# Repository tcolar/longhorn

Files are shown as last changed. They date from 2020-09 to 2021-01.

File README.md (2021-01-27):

# Longhorn keyboard build

What is the longhorn keyboard ?

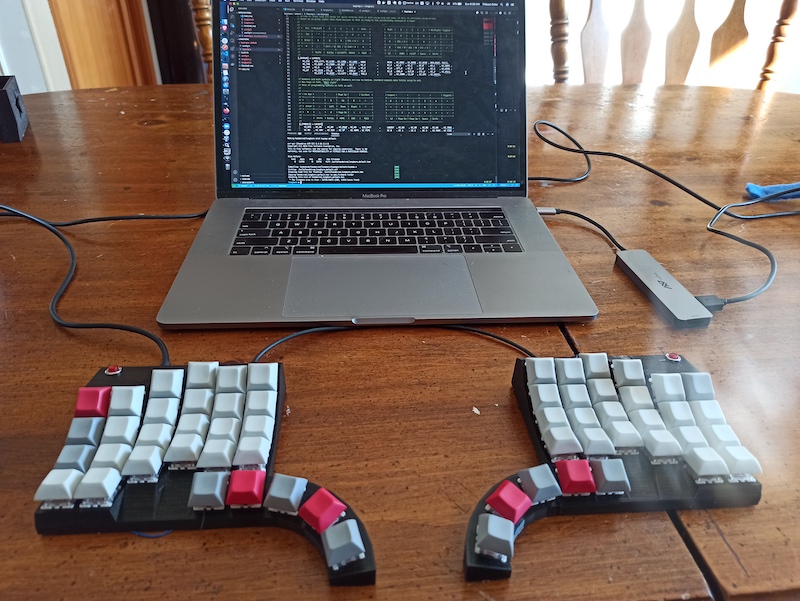
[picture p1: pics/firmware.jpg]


It's a split, sculpted, ortholinear keyboard.

It's a modified version of this keyboard by u/cyanophage : https://www.reddit.com/r/ErgoMechKeyboards/comments/i8e9xv/my_first_split_my_own_design/

Almost all the credits go to him, I ust modified his design, mostly to have a different thumb keys layout (fan out).

### Why is it called longhorn?

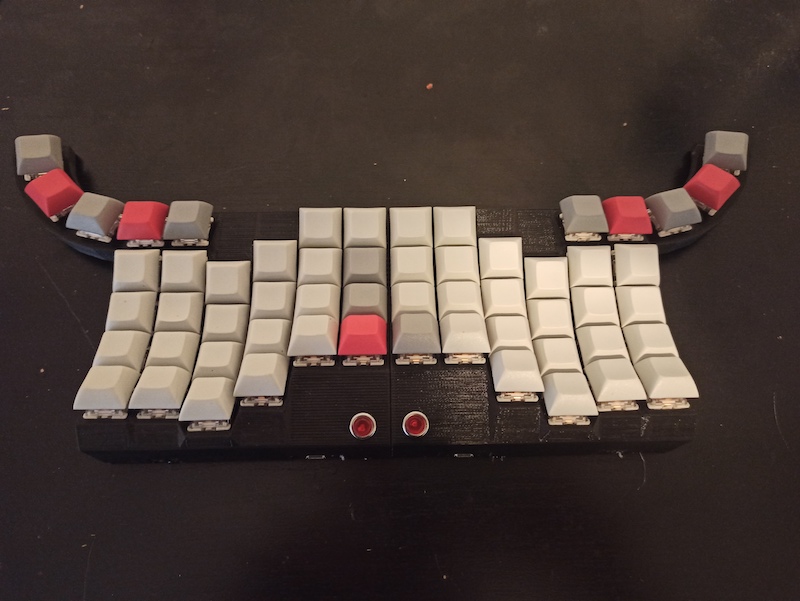
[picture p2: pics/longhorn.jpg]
longhorn
because: 

### Design

I started with the design by u/cyanophage and made some modifications.

- Removed the existing thumb keys.
- Replaced with a new circular thumb clusters.
- Added a caddy for the pro-micro (slightly different than the eliteC )
- Added a different jack caddy (jack module)

I used [OpenScad](https://www.openscad.org/) to tweak the design, in a linux VM as it's not signed to run on OSX.

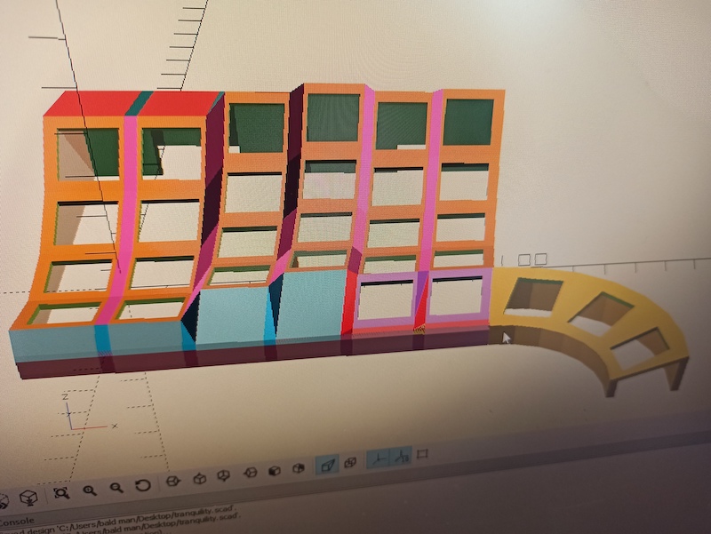
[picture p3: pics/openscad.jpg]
openscad


See the [Design](/design) folder for the Scad and STL files

### Printing

Here is the STL [kb.stl](design/kb.stl), printed mirrored for the other hand.

I printed with my old Robo3D+ using black PLA filament.

I used [Cura](https://ultimaker.com/software/ultimaker-cura) for the slicing.

I print via [octopi](https://octoprint.org/) (raspberry pi connected to the printer).

Settings I used:

- Bed Temp: 50c
- Extruder temp: 210c
- Quality : fine (0.2mm)
- Support: yes, zig-zag. This needs good support and zig zag is fast and easy to remove
- Adhesion: used a raft, adds almost an hour to the print, but support adhesion to the bed was an issue without it.

Print time: ~ 9 hours per side.

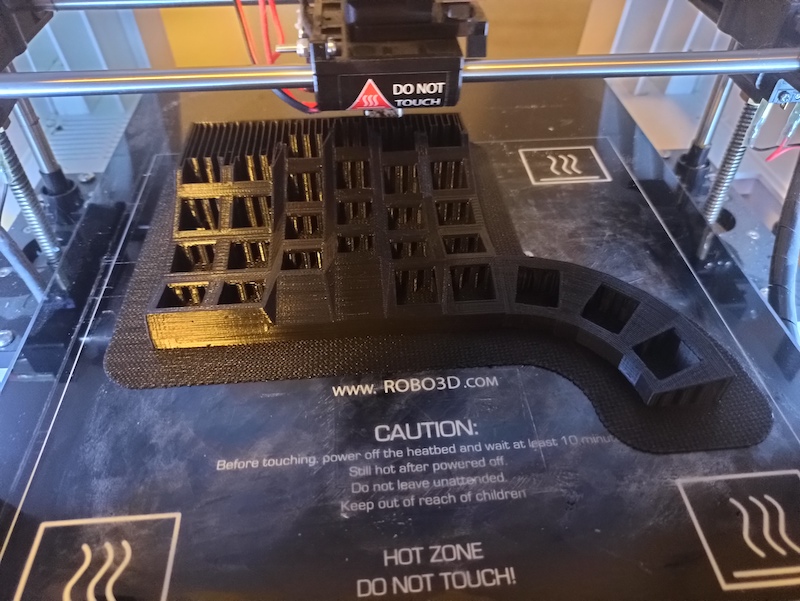
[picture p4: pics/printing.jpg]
printing


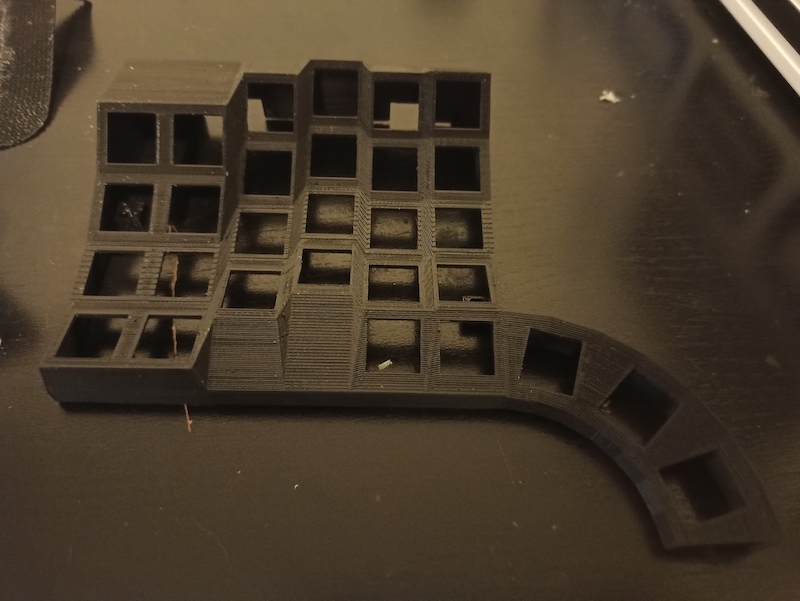
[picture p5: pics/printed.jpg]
printed


### Parts

- wire 22awg solid : https://www.amazon.com/gp/product/B07TX6BX47/ref=ppx_yo_dt_b_asin_title_o05_s00?ie=UTF8&psc=1
- Keyboard switches(60+), for example: https://www.amazon.com/gp/product/B07X3SYQMV/ref=ppx_yo_dt_b_asin_title_o09_s00?ie=UTF8&psc=1
- 4pins TRSS jacks (2+): https://www.amazon.com/gp/product/B08331SNXD/ref=ppx_yo_dt_b_asin_title_o00_s00?ie=UTF8&psc=1
- 1N4148 Diodes (60+) : https://www.amazon.com/gp/product/B06XB1R2NK/ref=ppx_yo_dt_b_asin_title_o02_s01?ie=UTF8&psc=1
- Keycaps (60+): Any but cheap ones for starters: https://www.amazon.com/gp/product/B07GP29DQF/ref=ppx_yo_dt_b_asin_title_o02_s02?ie=UTF8&psc=1
- ProMicro controllers (2+) : https://www.amazon.com/gp/product/B08BJNV1J3/ref=ppx_yo_dt_b_asin_title_o02_s02?ie=UTF8&psc=1
- Optional: Ribbon wire: https://www.amazon.com/gp/product/B07PBGVCNL/ref=ppx_yo_dt_b_asin_title_o02_s00?ie=UTF8&psc=1
- Optional: small reset buttons: https://www.amazon.com/gp/product/B07ZV3PB26/ref=ppx_yo_dt_b_asin_title_o07_s00?ie=UTF8&psc=1

### Tools:

- Soldering iron + solder
- Small wire cutters / strippers
- Hot glue gun
- Helping hands really helps : https://www.amazon.com/Neiko-01902-Adjustable-Magnifying-Alligator/dp/B000P42O3C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

### Switches

Install all the switches

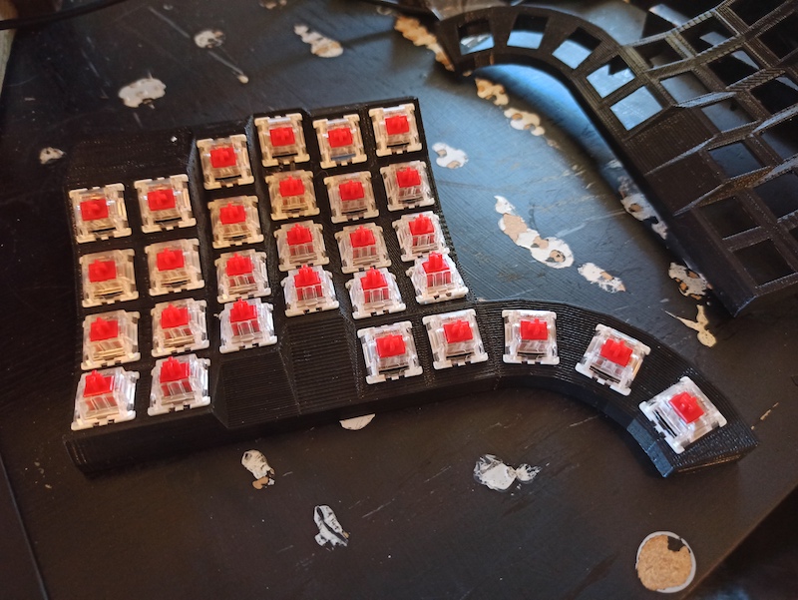
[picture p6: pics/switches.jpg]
switches


Then glue them in place:

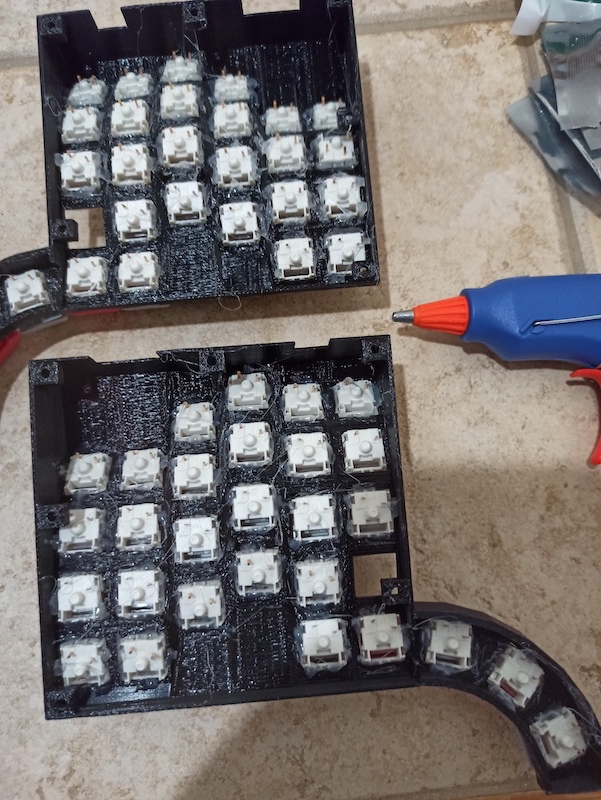
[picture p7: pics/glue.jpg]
glue


Testing pinky/thumb placement :

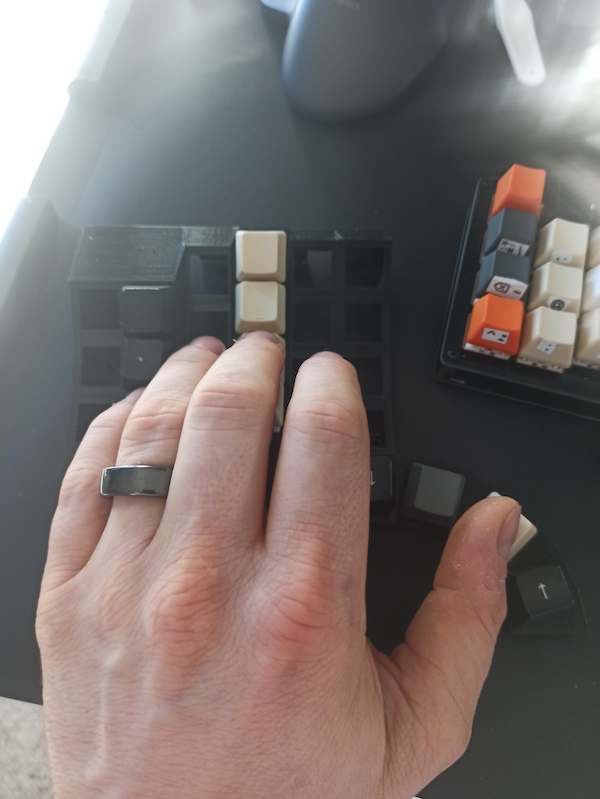
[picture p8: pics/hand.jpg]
hand


### Install keycaops

You can do this either now or after the wiring, but better know if anything is off ASAP.

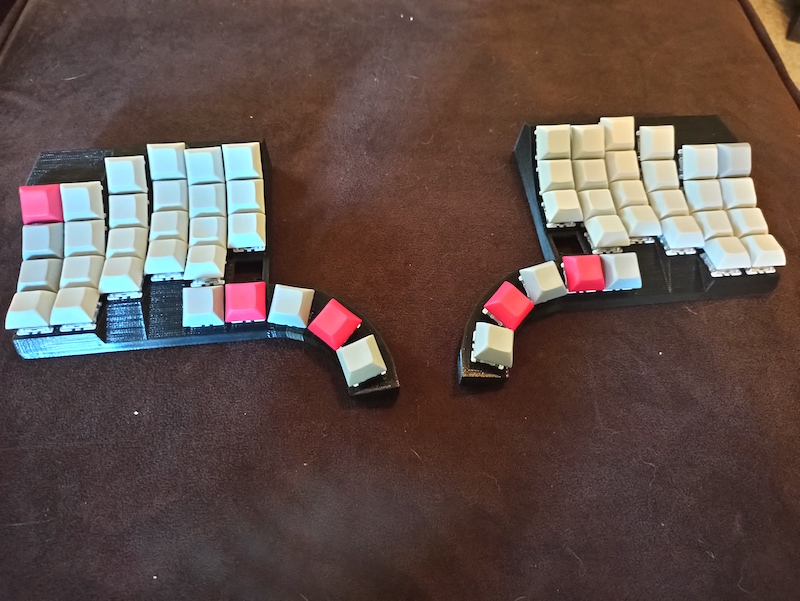
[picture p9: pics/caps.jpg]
caps


### Wiring

This is the part that is a ton of work.

My matrix is 6 cols \* 5 rows (per hand)
The thumb cluster is treated as row5 with keys in cols 2-6.

#### Rows

First I wired the rows, each key gets a diode to the row to avoid ghosting.

Make a little loop with each diode and solder it to each key.

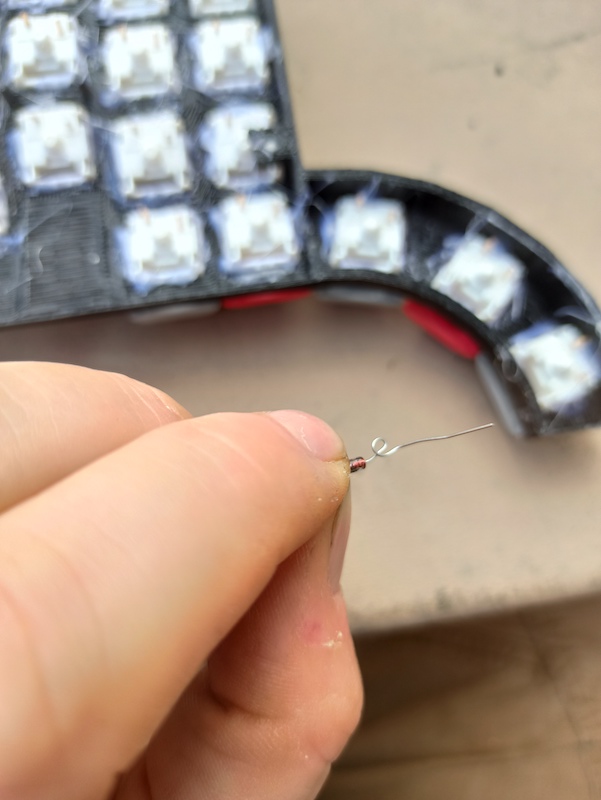
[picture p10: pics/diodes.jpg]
diodes


Then I take a piece of wire and mark the diode pins location and use a razor knife to expose the wire core. Make surer to use solid wire for this, stranded wire would be a pain.

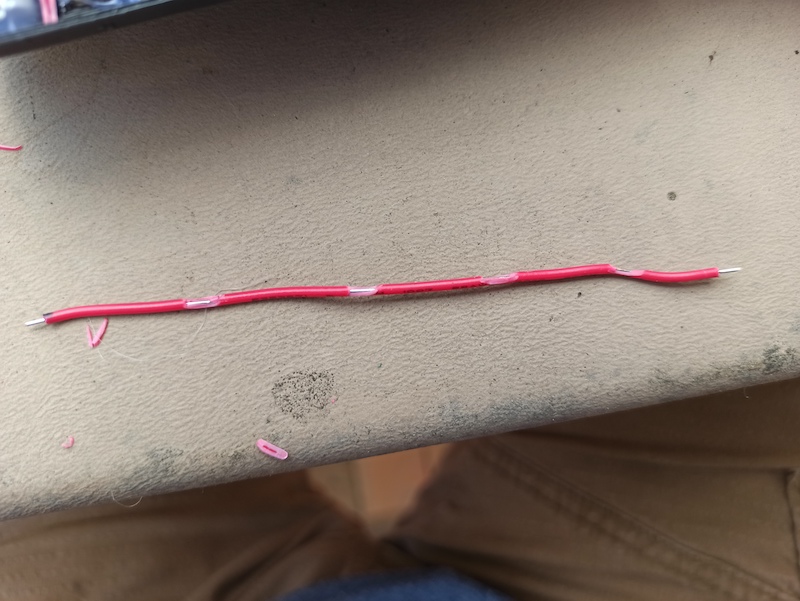
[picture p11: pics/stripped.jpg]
stripped


Then solder the diodes to the wire, and that's one row :
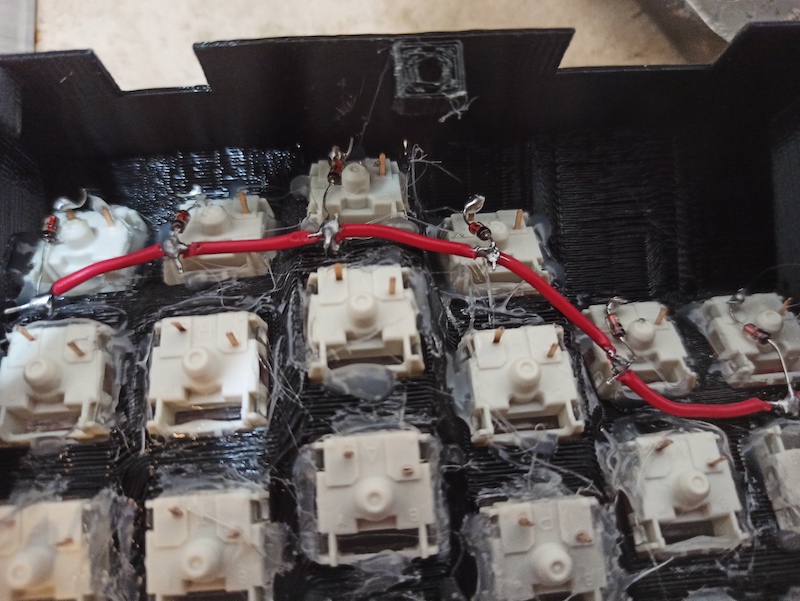
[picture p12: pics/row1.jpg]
row1


Repeat for all rows
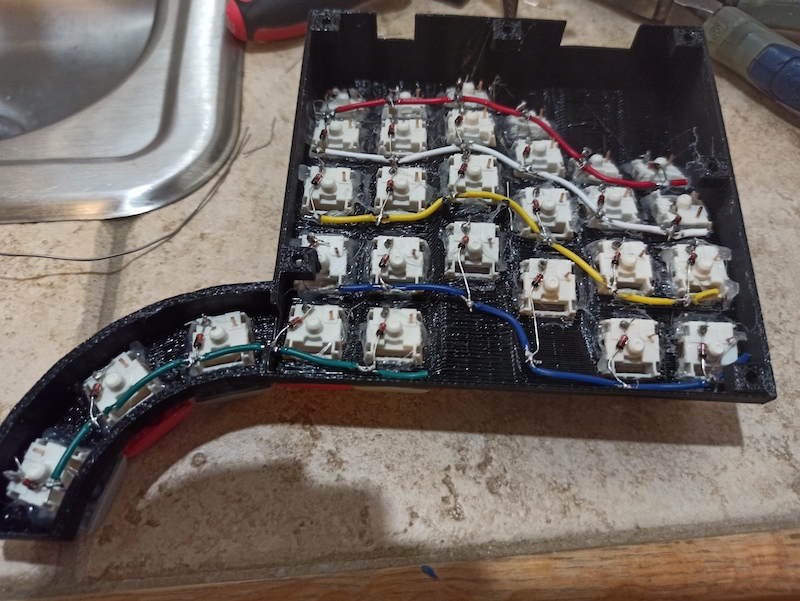
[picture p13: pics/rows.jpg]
rows


### Columns

For the columns we don't need any diodes just connect with wire:

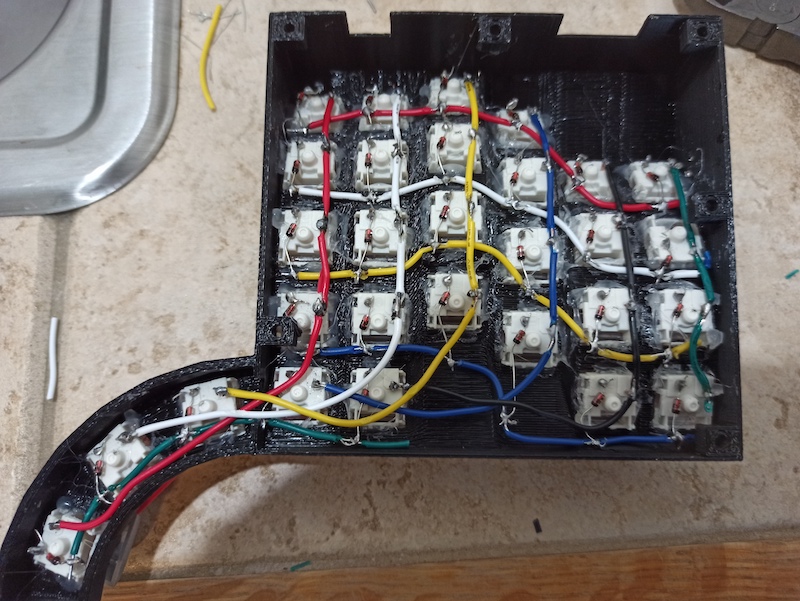
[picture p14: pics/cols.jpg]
cols


### Controller

Printed a caddy for the controller and jacks, see [micro.stl](design/micro.stl)

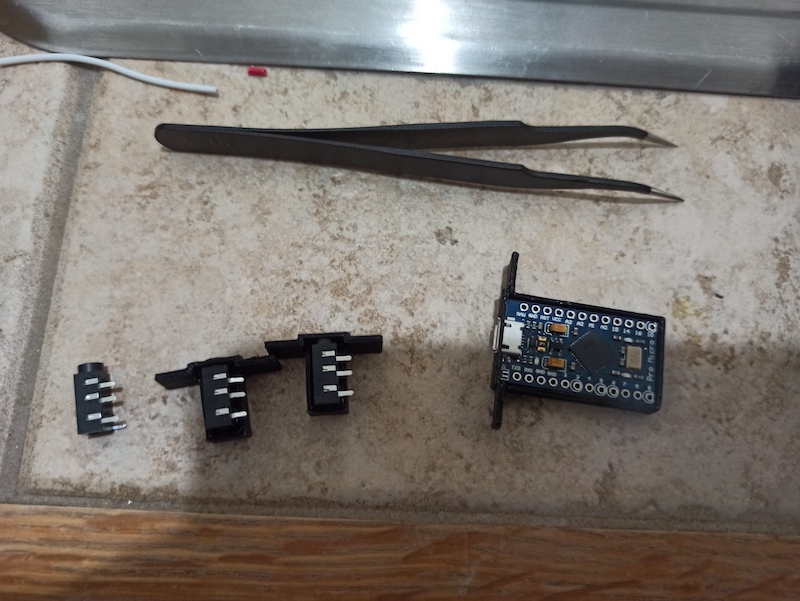
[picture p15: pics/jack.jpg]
jack


Wiring the controller os pretty difficult as it's very tiny and close together.

I used ribbon wire for this as it's less messy.

Here are the pins layout for the pro micro:
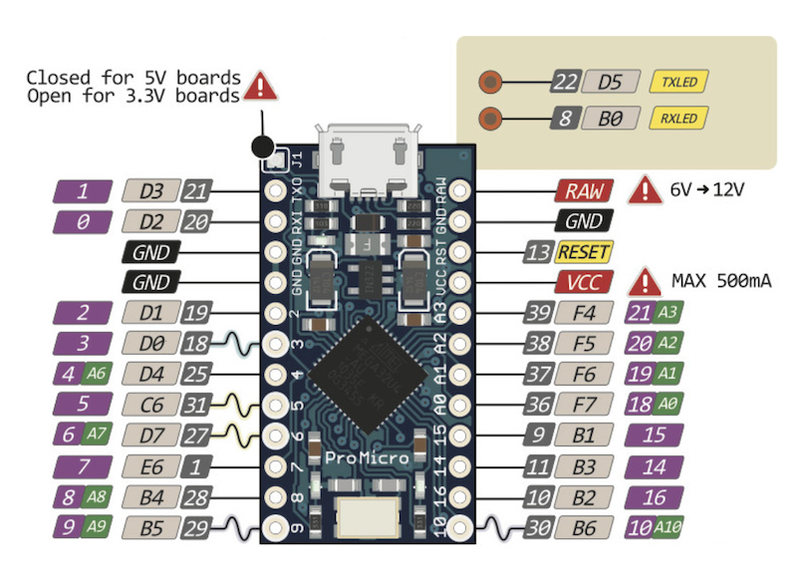
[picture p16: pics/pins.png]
pins


So first I soldered ribbon wires to the pro micro:

Best is to apply solder to the pro micro pins (little solder bubble), apply a bit of solder to the end of the wire, and then solder them together one by one.

Be careful not to have two pins getting soldered together.

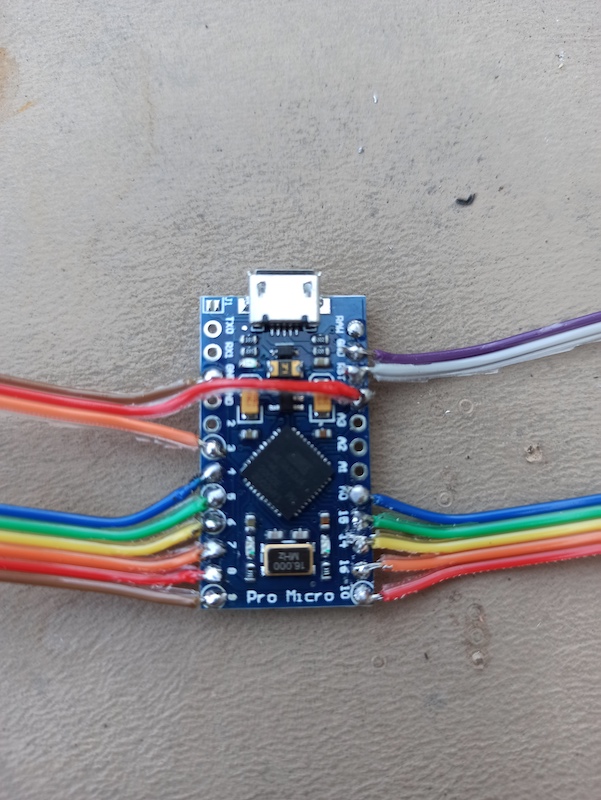
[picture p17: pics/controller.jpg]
controller


What I have here is:

- top right : purple(GND) and white(RESET) wires are and going to the reset button.
- top left : orange(pin3 a.k.a D0), red(VCC) and brown(GND), goes to the TRSS jack connecting the two halves.
- bottom right : wires going to the 5 columns.
- bottom left : wires going to the 6 rows.

Wired up, with the TRSS & controller caddies glued:

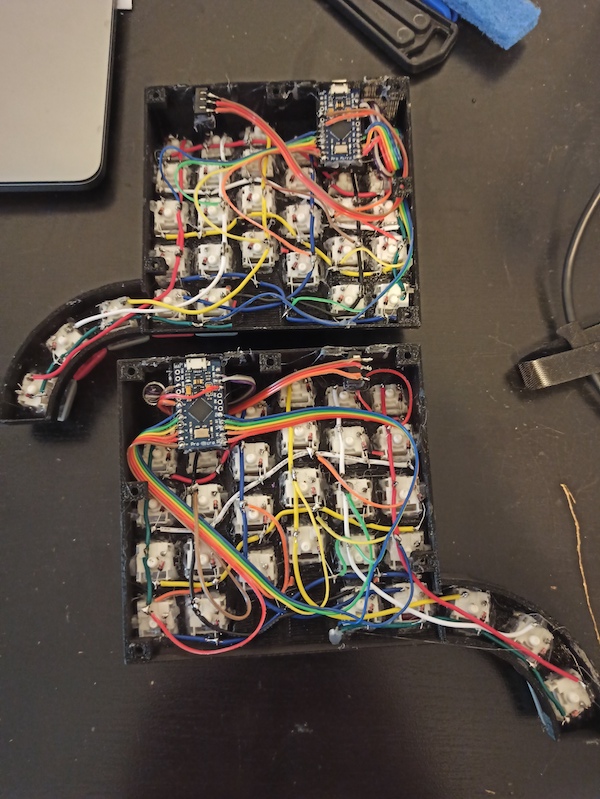
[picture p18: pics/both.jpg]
both


### Jacks & Reset button

I glued the [jack.stl](design/jack.stl) caddies and wired the jacks.

Note: I messed the jacks up and had to redo them as I initially let some hot glue get inside the jack plug and they were not working.

I had not planned for reset buttons, so I drilled a hole to add them, I highly recommend reset buttons as it makes it so much easier to reflash your firmware as you figure out your keymap.

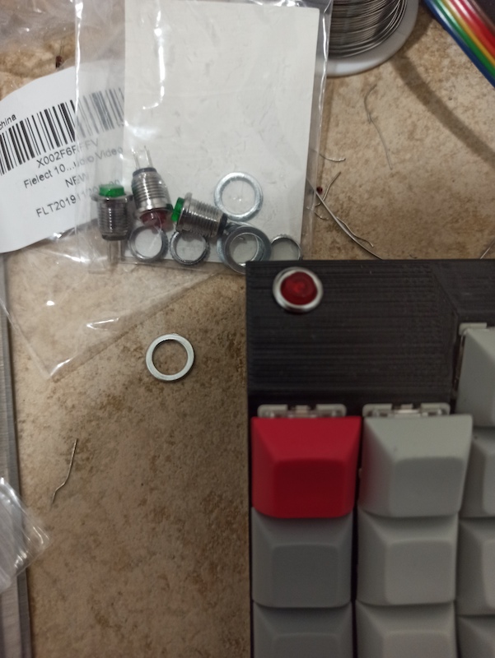
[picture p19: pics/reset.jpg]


### Firmware

Up next is the firmware.

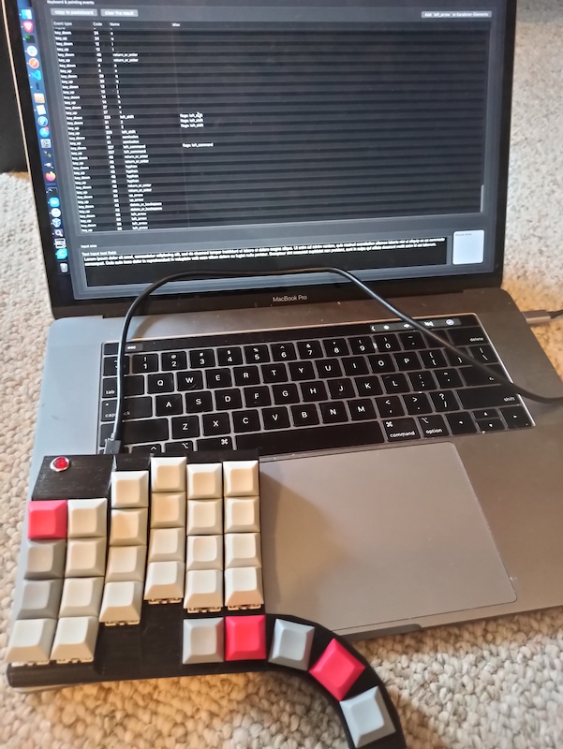
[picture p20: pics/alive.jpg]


I created my 5\*6 matrixes and my custom layout and flashed them.

#### rules.mk

in [rules.mk](/qmk_firmware/keyboards/handwired/longhorn/rules.mk), most important parts:

```yaml
# config for pro micro :
MCU = atmega32u4
BOOTLOADER = caterina
# Yes, this is a split KB :
SPLIT_KEYBOARD = yes
```

#### config.h

First [config.h](/qmk_firmware/keyboards/handwired/longhorn/config.h), the most important bits are:

```c
// Specify what micro-controller pins are hoked up to rows and cols:
// Note: the pin names are no what is labelled on the pro-micro, see
// the pin diagram above in this page for reference.
#define MATRIX_ROW_PINS \
    { B6, B2, B3, B1, F7 }
#define MATRIX_COL_PINS \
    { B4, B5, E6, D7, C6, D4 }
// Specify the pin used for serial communicationbetween the halves,
// via the audio cable.
#define SOFT_SERIAL_PIN D0      // pin #3
// Specify our diodes directions, if you set that wrong, keys won't work
#define DIODE_DIRECTION COL2ROW
```

#### longhorn.h

[longhorn.h](/qmk_firmware/keyboards/handwired/longhorn/longhorn.h) defines our key matrix and how keys are laid out on each half.

Note that I wired up my columns "mirrored" (left to right on left hand, right t eft on right hand), so I had to invert the right hand entries in my layout to get the correct mapping, see the file for more info.

#### keymap.c

Finally [keymap.c](/qmk_firmware/keyboards/handwired/longhorn/keymaps/default/keymap.c) contains our keyboard layout (with multi layers etc ...)

Just open the file to see my current layout.

#### Flashing

First I built my firmware with build.sh

```
qmk compile -kb handwired/longhorn -km default
```

And then flashed it using [QMK Toolbox](https://qmk.fm/toolbox/)

It works best to use auto-flash and then press the kb reset button (auto-flash because pro-micro only gives you ~8 seconds to flash after pressing reset).

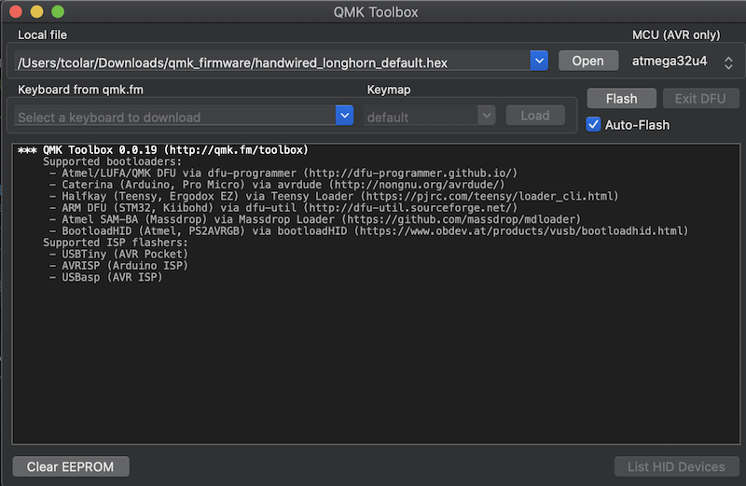
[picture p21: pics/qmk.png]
qmk


### End result:

It works great, next up is figuring out some baseplate and tenting, maybe 3D printed, maybe wood.

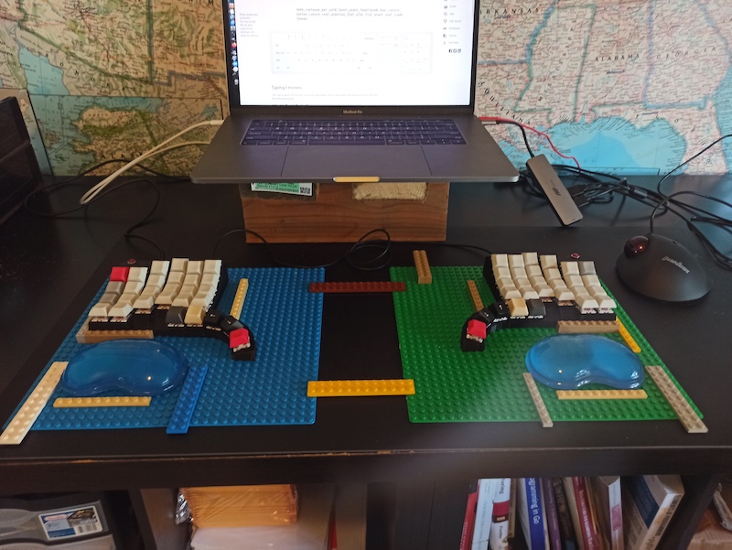
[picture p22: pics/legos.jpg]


Once I found the spacing and angle I like I made a "plank" for it, and my wife painted our pets on it.

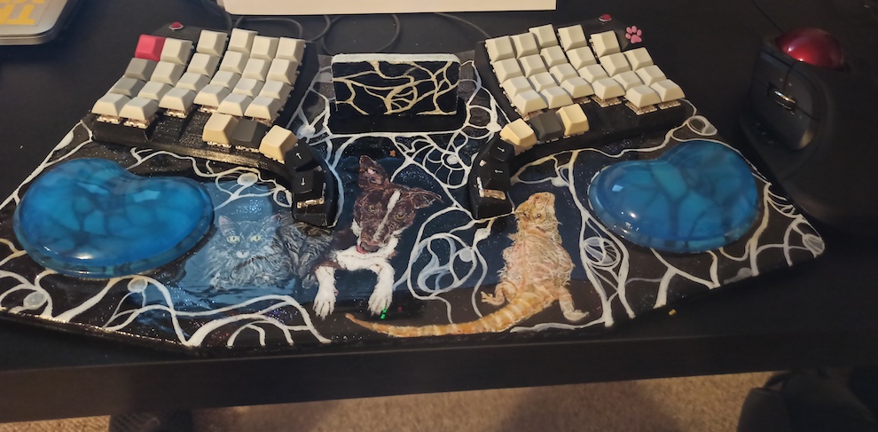
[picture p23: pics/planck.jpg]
plank


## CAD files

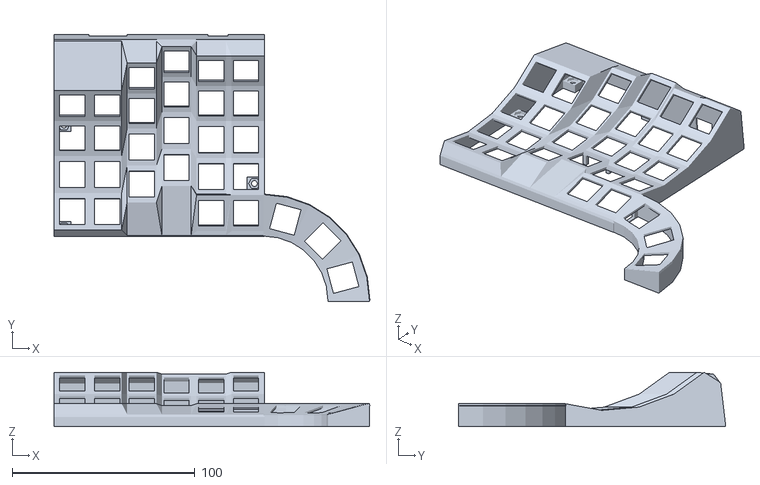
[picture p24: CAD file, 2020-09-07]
design/kb.stl
172.8 x 146.0 x 29.7

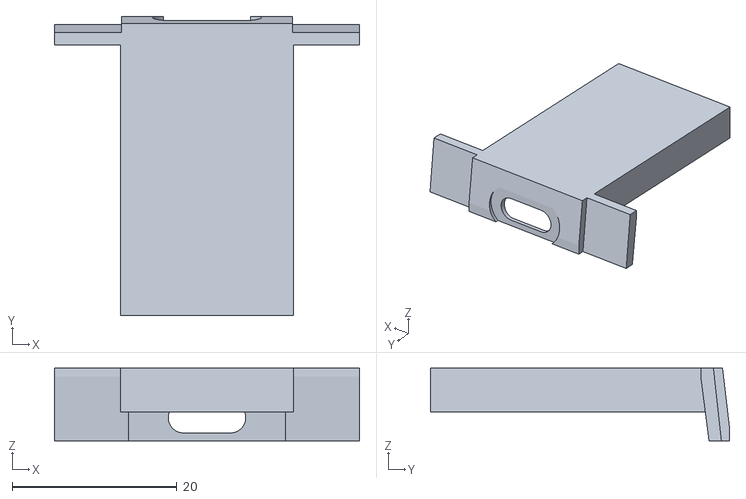
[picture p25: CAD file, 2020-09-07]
design/micro.stl
37.0 x 36.3 x 8.80

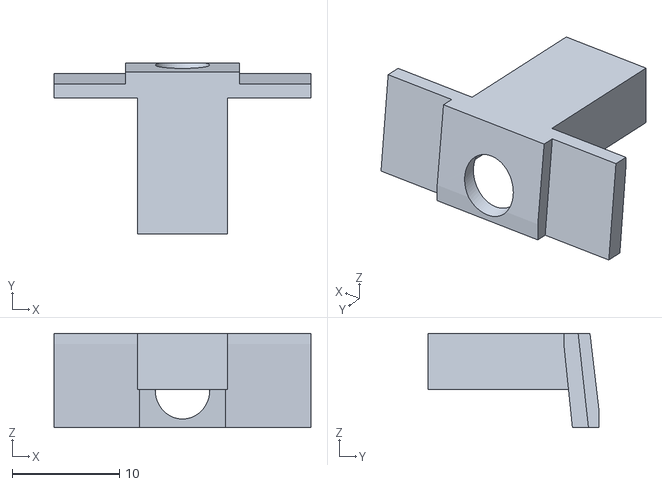
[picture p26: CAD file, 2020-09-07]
design/jack.stl
24.0 x 16.0 x 8.80

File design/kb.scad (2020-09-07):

kw=13.92; // size of hole for switch x
kd=14.42; // size of hole for switch y
sepx=19; // x spacing between the switches
sepy=20.6; // y spacing between the switches
th=1.5; // thickness of top
bth=1; // bottom thickness
gap=1.5; // x width of bits between keys

fingers = [0,0,15,24,19,19,19]; // controls y adjustment of columns
thumbs = [0,0,0,0,0,0,0];
dips = [0,0,0,1,1,0,0]; // controls z adjustment of columns
fronty=-33.5;  // y position of front
reary=76;      // y position of rear
supports = [fronty,-10,10,30,76];
edgex=2;


module rotate_about_xy(x, y, pt) {
  translate(pt)
    rotate([x, y, 0])
      translate(-pt)
        children();
}  

module rotate_about_z(z, pt) {
  translate(pt)
    rotate([0, 0, z])
      translate(-pt)
        children();
}  
module rotate_about_xy_off(x, y, pt,off) {
  translate(pt+off)
    rotate([x, y, 0])
      translate(-pt)
        children();
}  

bigR = 77;  // controls the radius of the curvature of the top. higher is less curve
rx = 2*asin(sepy/(2*bigR));
ry = 2*asin(sepx/(2*bigR));

// top plate

cubex=0.01;
cube2=cubex/2;
cubey=0.1;
vth=0.8;
baseline = -5; // controls where the bottom is and therefore overall height
frontdip=5; // height of bit at the front. higher numbers makes it lower
reardip=4;  // same at back
screw=6.1;

rotation_point = [0,0,bigR];
rot2 = 5; // how much the top is tilted forward
rot_point2 = [0,-30,2.7]; // the point forward tilt is around


module elitec() {
  color("green")cube([18.5,33.25,1.00],true);
//  color("silver")translate([0,(33.25/2)-(7.35/2)+0.65,1.65+0.5]) cube([9,7.35,3.3],true);
  color("silver") translate([0,(33.25/2)+0.65,1.65+0.5])
  difference() {
    hull() {
      translate([2.85,0,0]) rotate([90,0,0]) cylinder(d1=3.3,d2=3.3,h=7.35,$fn=32);
      translate([-2.85,0,0]) rotate([90,0,0]) cylinder(d1=3.3,d2=3.3,h=7.35,$fn=32);
    }
    hull() {
      translate([2.85,1,0]) rotate([90,0,0]) cylinder(d1=2.9,d2=2.9,h=7.35,$fn=32);
      translate([-2.85,1,0]) rotate([90,0,0]) cylinder(d1=2.9,d2=2.9,h=7.35,$fn=32);
    }
  }
  color("gray") translate([0,-2,1]) cube([8,8,1],true);
}

module elitec4() {
  difference() {
    color("green")translate([0,0,0.33]) cube([18.5,33.25,1.66],true);
    translate([0,13.13,0]) cube([9,7,1.67],true);
   
  }
//  color("silver")translate([0,(33.25/2)-(7.35/2)+0.65,1.65+0.5]) cube([9,7.35,3.3],true);
  color("silver") translate([0,(33.25/2)+0.65,1.16])
  difference() {
    hull() {
      translate([2.85,0,0]) rotate([90,0,0]) cylinder(d1=3.3,d2=3.3,h=7.35,$fn=32);
      translate([-2.85,0,0]) rotate([90,0,0]) cylinder(d1=3.3,d2=3.3,h=7.35,$fn=32);
    }
    hull() {
      translate([2.85,1,0]) rotate([90,0,0]) cylinder(d1=2.9,d2=2.9,h=7.35,$fn=32);
      translate([-2.85,1,0]) rotate([90,0,0]) cylinder(d1=2.9,d2=2.9,h=7.35,$fn=32);
    }
  }
  color("gray") translate([0,-2,1]) cube([8,8,1],true);
 
}

module pro_micro_caddy() {
  difference() {
    intersection() {
      color("limegreen")hull() {
       // top left
       translate([-10,fingers[3]+3,-dips[3]-reardip]) rotate_about_xy(rot2,0,rot_point2) rotate_about_xy(rx*3-rx/2,0,rotation_point) cube([cubex, cubey, th],true);
       // top right
       translate([30,fingers[3]+3,-dips[3]-reardip]) rotate_about_xy(rot2,0,rot_point2) rotate_about_xy(rx*3-rx/2,0,rotation_point) cube([cubex, cubey, th],true);
       // bottom left
       translate([-10,reary,baseline]) cube([cubex, 1, th],true);
       // bottom right
       translate([30,reary,baseline]) cube([cubex, 1, th],true);
     }
     translate([10,17.2+58+1,-3.5+1.75-0.2]) cube([20.7,5,10],true); // back plate
   }
   // hole for usb cable plug
    translate([10,78,-2.95]) hull() {
      translate([2.85,0,0]) rotate([90,0,0]) cylinder(d1=3.7,d2=3.7,h=7.35,$fn=32);
      translate([-2.85,0,0]) rotate([90,0,0]) cylinder(d1=3.7,d2=3.7,h=7.35,$fn=32);
    }
    // spacing for usb cable around the plug
    color("teal")translate([10,79,-2.95])rotate([90,90,0]) hull() {
      translate([0,2.95,0])cylinder(d1=7.3,d2=7.3,h=3,$fn=64);
      translate([0,-2.95,0])cylinder(d1=7.3,d2=7.3,h=3,$fn=64);
    }
  }
 
  // bit to glue caddy to case
  difference() {
    union() {
      hull() {
        translate([-4,75,-5.25]) cube([9,2,1],true);
        translate([-4,74,2.55]) cube([9,2,1],true);
      }
      hull() {
        translate([24,75,-5.25]) cube([9,2,1],true);
        translate([24,74,2.55]) cube([9,2,1],true);
      }
      translate([10,58,0.25]) {
        difference() {
          union() {
            translate([0,-0.4,1])color("lightblue")cube([21,34.8,1.00],true); // base
            translate([0,-0.4,2])color("lightcoral")cube([21,34.8,1.6],true); // base
          }
          translate([8,-0.4,0]) cube([3,32.8,3], true);
          translate([-8,-0.4,0]) cube([3,32.8,3], true);
          translate([0,-15.3,0]) cube([13.1,3,3], true);
        }
       
        // short walls
        color("orange")translate([10,0,-1]) cube([1,34,3],true);
        color("orange")translate([-10,0,-1]) cube([1,34,3],true);
        color("orange")translate([0,-17.3,-1]) cube([21,1,3],true);
      }
    }
    hull() {
       // top left
       translate([-10,fingers[3]+3,-dips[3]-reardip]) rotate_about_xy(rot2,0,rot_point2) rotate_about_xy(rx*3-rx/2,0,rotation_point) cube([cubex, cubey, th],true);
       // top right
       translate([30,fingers[3]+3,-dips[3]-reardip]) rotate_about_xy(rot2,0,rot_point2) rotate_about_xy(rx*3-rx/2,0,rotation_point) cube([cubex, cubey, th],true);
       // bottom left
       translate([-10,reary,baseline]) cube([cubex, 1, th],true);
       // bottom right
       translate([30,reary,baseline]) cube([cubex, 1, th],true);
     }
  }
}

// caddy to hold the elite c v4
module caddy1_v4() {
  difference() {
    intersection() {
      color("limegreen")hull() {
       // top left
       translate([-10,fingers[3]+3,-dips[3]-reardip]) rotate_about_xy(rot2,0,rot_point2) rotate_about_xy(rx*3-rx/2,0,rotation_point) cube([cubex, cubey, th],true);
       // top right
       translate([30,fingers[3]+3,-dips[3]-reardip]) rotate_about_xy(rot2,0,rot_point2) rotate_about_xy(rx*3-rx/2,0,rotation_point) cube([cubex, cubey, th],true);
       // bottom left
       translate([-10,reary,baseline]) cube([cubex, 1, th],true);
       // bottom right
       translate([30,reary,baseline]) cube([cubex, 1, th],true);
     }
     translate([10,17.2+58+1,-3.5+1.75-0.2]) cube([20.7,5,10],true); // back plate
   }
   // hole for usb cable plug
    translate([10,78,-1.95]) hull() {
      translate([2.85,0,0]) rotate([90,0,0]) cylinder(d1=3.7,d2=3.7,h=7.35,$fn=32);
      translate([-2.85,0,0]) rotate([90,0,0]) cylinder(d1=3.7,d2=3.7,h=7.35,$fn=32);
    }
    color("teal")translate([10,79,-1.95])rotate([90,90,0]) hull() {
      translate([0,2.95,0])cylinder(d1=7.3,d2=7.3,h=3,$fn=64);
      translate([0,-2.95,0])cylinder(d1=7.3,d2=7.3,h=3,$fn=64);
    }
  }
 
  // bit to glue caddy to case
  difference() {
    union() {
      //translate([24.5,74.6,-1.35]) rotate([5,0,0]) cube([10,2,9],true);
      //translate([-4,74.6,-1.35]) rotate([5,0,0]) cube([9,2,9],true);
      hull() {
        translate([-4,75,-5.25]) cube([9,2,1],true);
        translate([-4,74,2.55]) cube([9,2,1],true);
      }
      hull() {
        translate([24,75,-5.25]) cube([9,2,1],true);
        translate([24,74,2.55]) cube([9,2,1],true);
      }
      translate([10,58,-0.75]) {
        difference() {
          union() {
            translate([0,-0.4,1])color("lightblue")cube([21,34.8,1.00],true); // base
            translate([0,-0.4,2.65])color("lightcoral")cube([21,34.8,2.3],true); // base
          }
          translate([8,-0.4,0]) cube([3,32.8,3], true);
          translate([-8,-0.4,0]) cube([3,32.8,3], true);
          translate([0,-15.3,0]) cube([13.1,3,3], true);
        }
        // short walls
        color("orange")translate([10,0,-1]) cube([1,34,3],true);
        color("orange")translate([-10,0,-1]) cube([1,34,3],true);
        color("orange")translate([0,-17.3,-1]) cube([21,1,3],true);
      }
    }
    // backplate
    hull() {
       // top left
       translate([-10,fingers[3]+3,-dips[3]-reardip]) rotate_about_xy(rot2,0,rot_point2) rotate_about_xy(rx*3-rx/2,0,rotation_point) cube([cubex, cubey, th],true);
       // top right
       translate([30,fingers[3]+3,-dips[3]-reardip]) rotate_about_xy(rot2,0,rot_point2) rotate_about_xy(rx*3-rx/2,0,rotation_point) cube([cubex, cubey, th],true);
       // bottom left
       translate([-10,reary,baseline]) cube([cubex, 1, th],true);
       // bottom right
       translate([30,reary,baseline]) cube([cubex, 1, th],true);
     }
   
  }
}
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

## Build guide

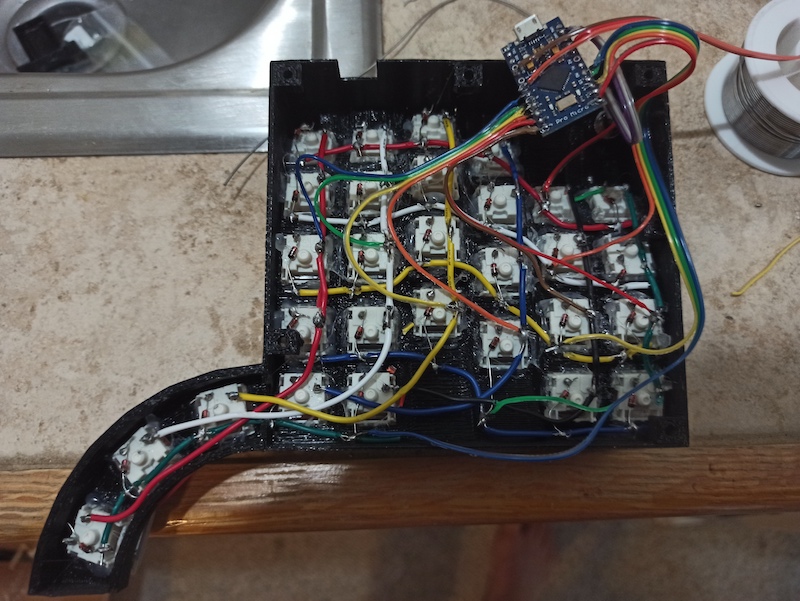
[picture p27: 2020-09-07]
pics/controller_wiring.jpg

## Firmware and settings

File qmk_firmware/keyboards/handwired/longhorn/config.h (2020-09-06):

#pragma once

#include "config_common.h"

/* USB Device descriptor parameter */
#define VENDOR_ID 0x2B10
#define PRODUCT_ID 0x2256
#define DEVICE_VER 0x0100
#define MANUFACTURER tcolar
#define PRODUCT Longhorn
#define DESCRIPTION Split keyboard 6*4 + thumbs


/* key matrix size */
// This is kinda confusing, I think it should be called MATRIX_ROWS_LENGTH
// We have 5 cols on each hand, so row length is 10
#define MATRIX_ROWS 10
#define MATRIX_COLS 6

// Wiring of each half
// See pro-micro pinout: https://golem.hu/article/pro-micro-pinout/
#define MATRIX_ROW_PINS \
    { B6, B2, B3, B1, F7 }
    
#define MATRIX_COL_PINS \
    { B4, B5, E6, D7, C6, D4 }

// we use serail communication on pin D0 betwen the 2 halves (via TRRS cable)
#define SOFT_SERIAL_PIN D0
#define SELECT_SOFT_SERIAL_SPEED 1

// Does not seem to have effect ...
#define SPLIT_HAND_PIN F4

/* COL2ROW or ROW2COL */
#define DIODE_DIRECTION COL2ROW

/* Set 0 if debouncing isn't needed */
#define DEBOUNCE 5

// Without this Hold/Tap keys are flaky for me (rollovers)
#define IGNORE_MOD_TAP_INTERRUPT
